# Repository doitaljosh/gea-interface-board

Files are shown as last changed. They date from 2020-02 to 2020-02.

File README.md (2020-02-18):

KiCAD Board Files for an open source adapter that allows hacking and protyping 
with GE appliances.

### Note: these haven't been tested or produced.

They are based off of GE's official implementation. I've reverse engineered an 
interface on an oven board, and this is essentially a half-duplex to full-duplex 
UART converter. It can talk to two appliances at once, as it has two channels.
A smaller, single channel variant is in the works.

#### RJ45 port pinout:
1. GND
2. GEA_E (half-duplex 19200 baud)
3. 9-14VDC
4. GEA2_RXD (full-duplex 230400 baud)
5. GEA2_TXD
6. 5V
7. NC
8. NC

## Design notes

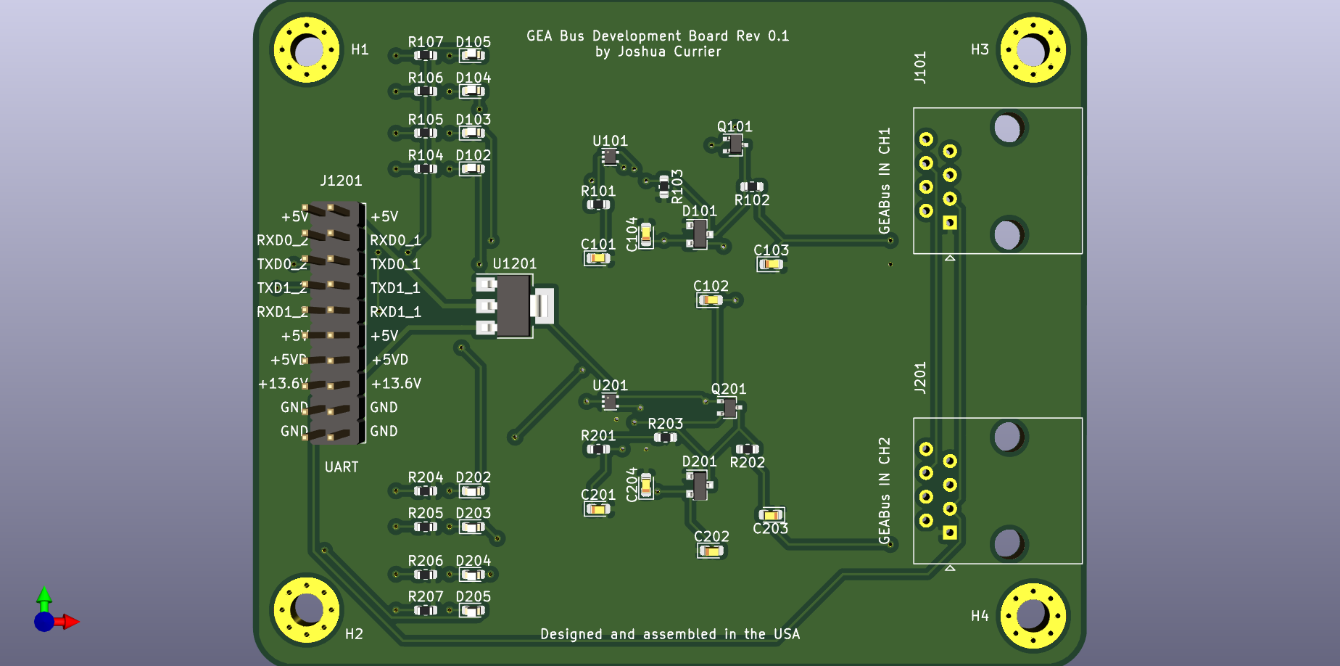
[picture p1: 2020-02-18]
top-hires.png

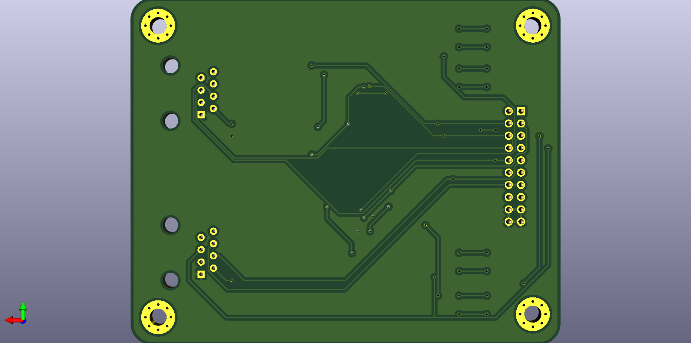
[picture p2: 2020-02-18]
bottom-hires.png

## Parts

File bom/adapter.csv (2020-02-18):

Id | Designator | Package | Quantity | Designation | Supplier and ref
1 | H4,H2,H3,H1 | MountingHole_3.5mm_Pad_Via | 4 | MountingHole_3.5mm_Pad_Via
2 | C101,C102,C103,C104,C201,C202,C203,C204 | CP_EIA-1608-10_AVX-L | 8 | 0.1u
3 | D101,D201 | SOT-23 | 2 | BAV99
4 | D102,D103,D104,D105,D202,D203,D204,D205 | LED_0603_1608Metric | 8 | LED
5 | J101 | RJ45_Amphenol_54602-x08_Horizontal | 1 | GEABus IN CH1
6 | J201 | RJ45_Amphenol_54602-x08_Horizontal | 1 | GEABus IN CH2
7 | J1201 | PinHeader_2x10_P2.54mm_Vertical | 1 | UART
8 | Q101,Q201 | SOT-323_SC-70 | 2 | DTA143X
9 | R101,R201 | R_0603_1608Metric | 2 | 47k
10 | R102,R202 | R_0603_1608Metric | 2 | 120
11 | R103,R203 | R_0603_1608Metric | 2 | 22k
12 | R104,R105,R106,R107,R204,R205,R206,R207 | R_0603_1608Metric | 8 | 330
13 | U101,U201 | SOT-553 | 2 | 74LVC1GU04DRL
14 | U1201 | SOT-223-3_TabPin2 | 1 | AMS1117-5.0

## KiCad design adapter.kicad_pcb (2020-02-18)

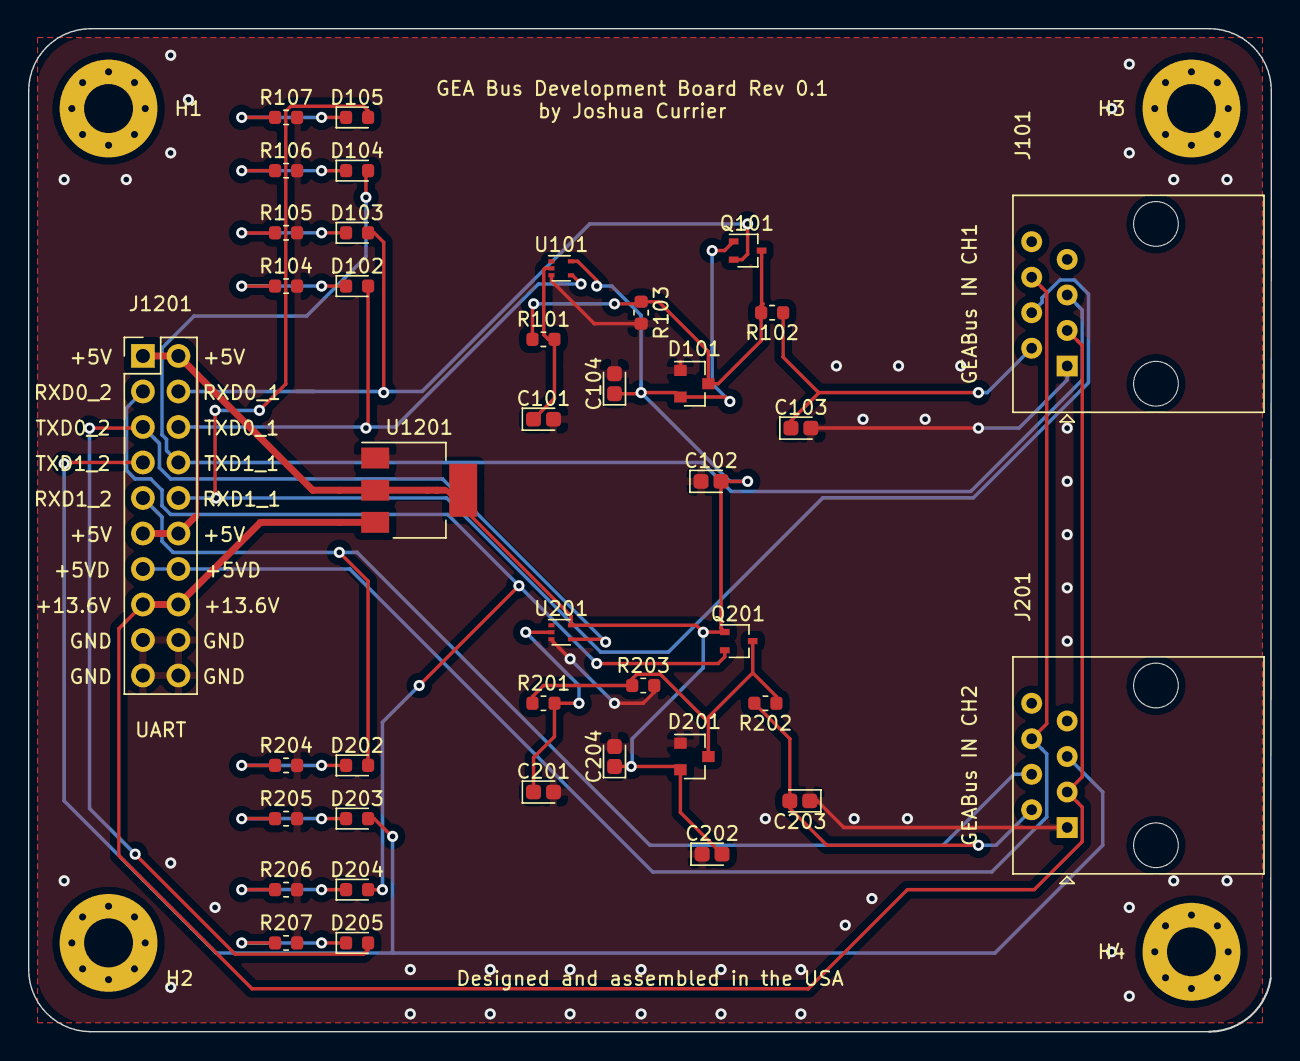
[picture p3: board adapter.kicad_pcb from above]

Board: 2 copper layers, 88.9 x 71.8 mm, 44 parts (0 on the bottom side), 26 nets.

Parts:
C101, C102, C103, C104, C201, C202, C203, C204: 0.1u; CP_EIA-1608-10_AVX-L
D101, D201: BAV99; SOT-23
D102, D103, D104, D105, D202, D203, D204, D205: LED; LED_0603_1608Metric
H1, H2, H3, H4: MountingHole_3.5mm_Pad_Via
J101: GEABus IN CH1; RJ45_Amphenol_54602-x08_Horizontal
J201: GEABus IN CH2; RJ45_Amphenol_54602-x08_Horizontal
J1201: UART; PinHeader_2x10_P2.54mm_Vertical
Q101, Q201: DTA143X; SOT-323_SC-70
R101, R201: 47k; R_0603_1608Metric
R102, R202: 120; R_0603_1608Metric
R103, R203: 22k; R_0603_1608Metric
R104, R105, R106, R107, R204, R205, R206, R207: 330; R_0603_1608Metric
U101, U201: 74LVC1GU04DRL; SOT-553
U1201: AMS1117-5.0; SOT-223-3_TabPin2

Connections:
+5V: C102.2, C104.1, C202.2, C204.1, D101.2, D201.2, J1201.1, J1201.2, J1201.11, J1201.12, Q101.1, Q201.1, U101.5, U201.5, U1201.2
GND: C101.2, C102.1, C103.2, C104.2, C201.2, C202.1, C203.1, C204.2, D101.1, D201.1, J101.1, J201.1, J1201.17, J1201.18, J1201.19, J1201.20, R103.2, R104.2, R105.2, R106.2, R107.2, R203.2, R204.2, R205.2, R206.2, R207.2, U101.3, U201.3, U1201.1
unnamed: C101.1, R101.2, U101.2
unnamed: C103.1, J101.2, R102.1
unnamed: C201.1, R201.2, U201.2
unnamed: C203.2, J201.2, R202.2
unnamed: D101.3, Q101.3, R101.1, R102.2, R103.1
unnamed: D102.1, R104.1
unnamed: D102.2, J1201.6, U101.4
unnamed: D103.1, R105.1
unnamed: D103.2, J1201.4, Q101.2
unnamed: D104.1, R106.1
unnamed: D104.2, J101.5, J1201.8
unnamed: D105.1, R107.1
unnamed: D105.2, J101.4, J1201.10
unnamed: D201.3, Q201.3, R201.1, R202.1, R203.1
unnamed: D202.1, R204.1
unnamed: D202.2, J201.4, J1201.9
unnamed: D203.1, R205.1
unnamed: D203.2, J201.5, J1201.7
unnamed: D204.1, R206.1
unnamed: D204.2, J1201.3, Q201.2
unnamed: D205.1, R207.1
unnamed: D205.2, J1201.5, U201.4
unnamed: J101.3, J201.3, J1201.15, J1201.16, U1201.3
unnamed: J101.6, J201.6, J1201.13, J1201.14
